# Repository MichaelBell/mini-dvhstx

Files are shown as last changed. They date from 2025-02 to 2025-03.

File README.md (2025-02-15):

# Mini RP2350 board for Digital Video

The RP2350's HSTX peripheral supports TMDS encoding, as needed for HDMI/DVI video.

The idea of this board is to provide a minimal board in a similar form factor to the Pico 2, but with an HDMI connector on it, to allow experimenting with HSTX and digital video.



My [DVI for HSTX](https://github.com/MichaelBell/dvhstx) library should be ideal for use with this board.

## Pinout

The left side is the same as the Pico, the right side is different (but somewhat related).

| Left Side | Right Side |
| --- | --- |
| GPIO 0 | VBUS |
| GPIO 1 | HDMI 5V |
| Ground | Ground |
| GPIO 2 | Not connected |
| GPIO 3 | +3V3 |
| GPIO 4 | GPIO 29 (ADC) |
| GPIO 5 | GPIO 28 (ADC) |
| Ground | Ground |
| GPIO 6 | GPIO 23 |
| GPIO 7 | GPIO 22 |
| GPIO 8 | SWD |
| GPIO 9 | SWCLK |
| Ground | Ground |
| GPIO 10 | |
| GPIO 11 | |
| HDMI HPD  | |

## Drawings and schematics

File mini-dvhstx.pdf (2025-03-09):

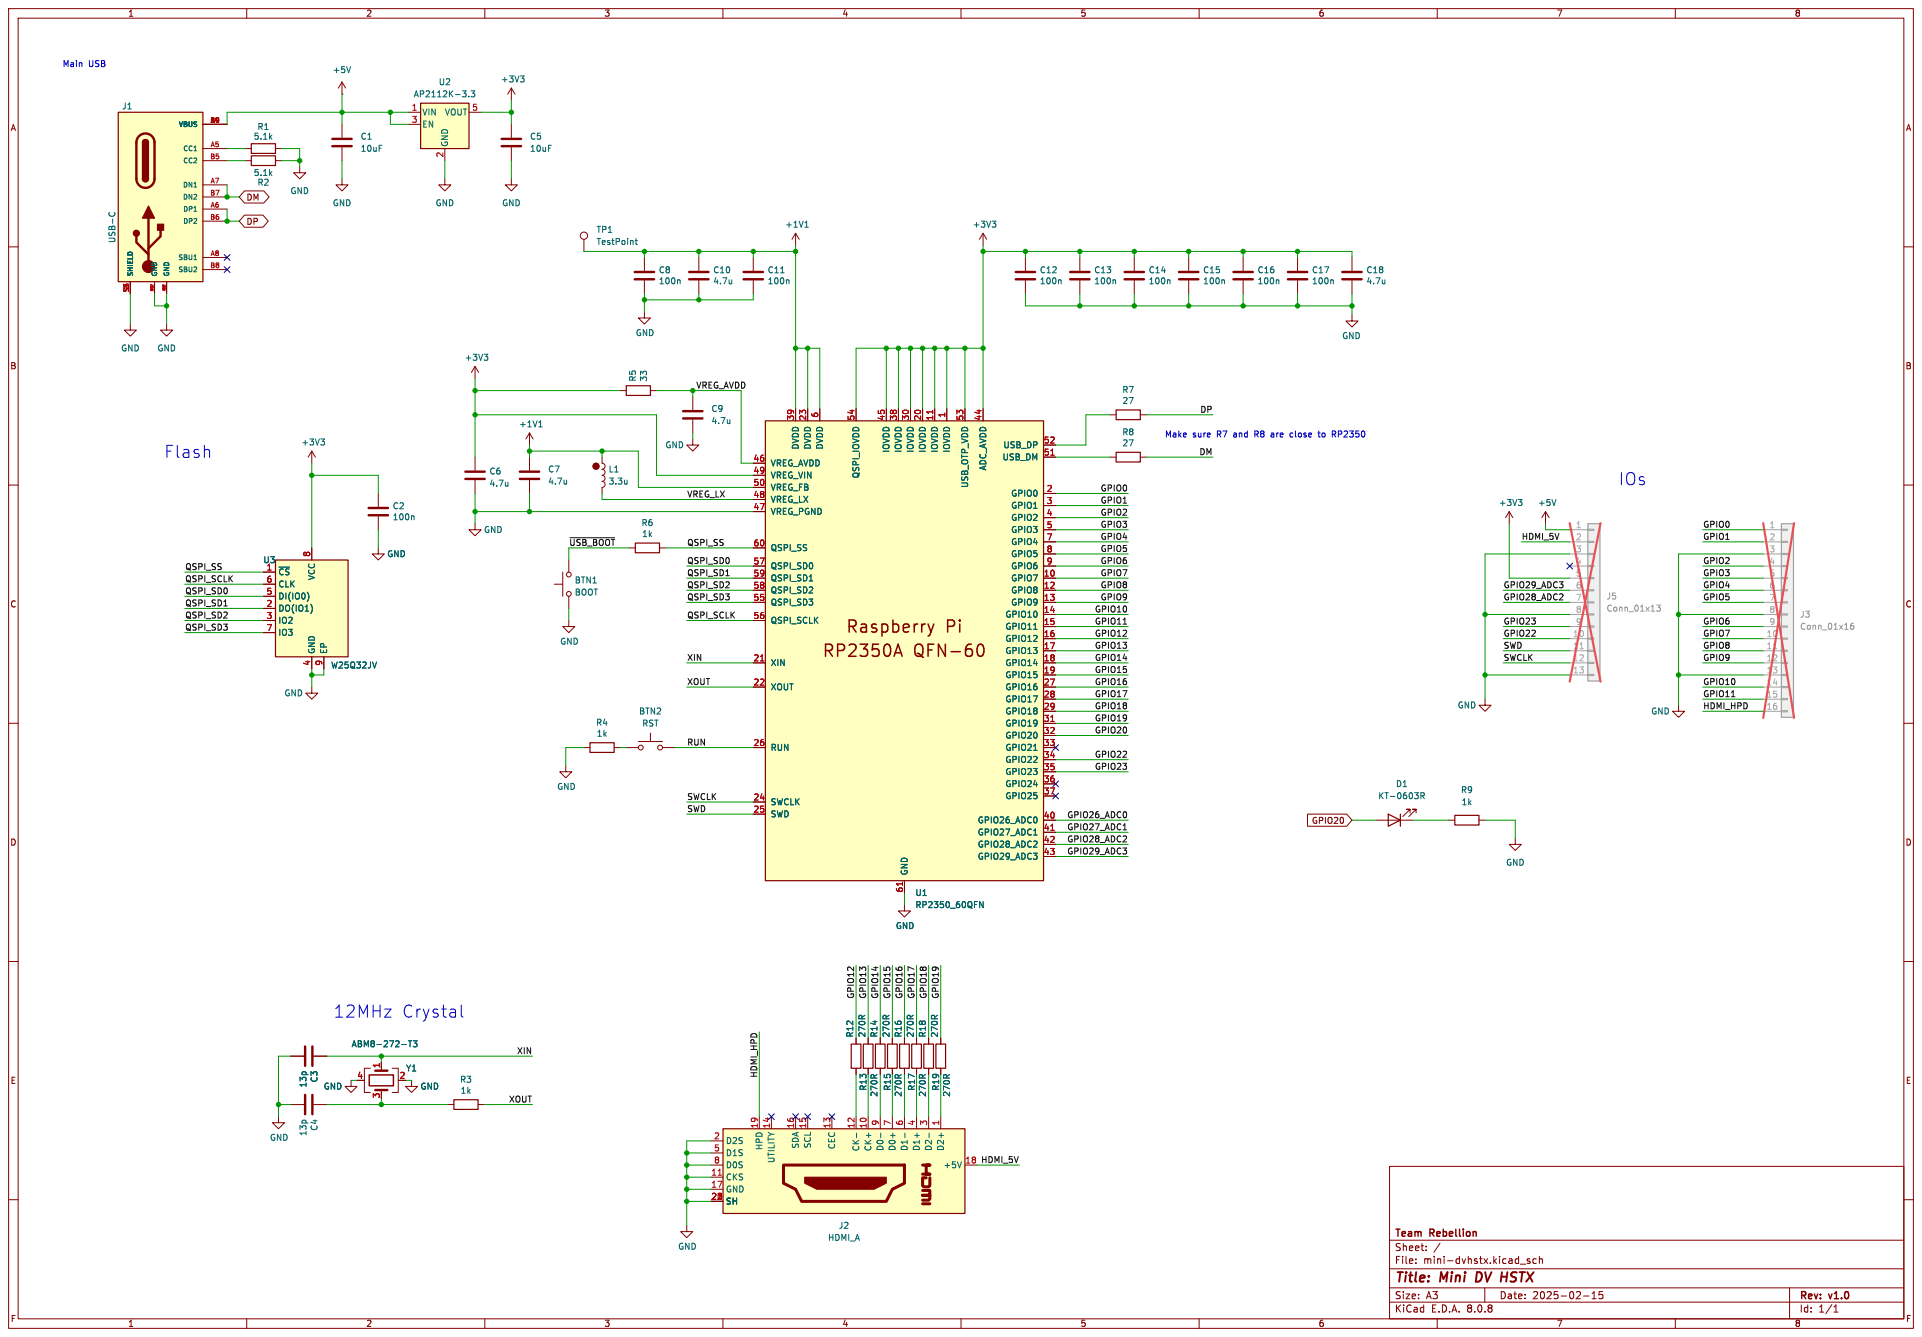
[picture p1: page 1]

1 CC1 A5 DP1 A6 DN1 A7 SBU1 A8 CC2 B5 DP2 B6 DN2 B7 SBU2 B8 SHIELD S34 GND A1 GND A12 VBUS A49 GND B1 GND B12 VBUS B49 SHIELD S1 J1 USB-C

1 GPIO7 10 IOVDD 11 GPIO8 12 GPIO9 13 GPIO10 14 GPIO11 15 GPIO12 16 GPIO13 17 GPIO14 18 GPIO15 19 GPIO0 2 IOVDD 20 XIN 21 XOUT 22 DVDD 23 SWCLK 24 SWD 25 RUN 26 GPIO16 27 GPIO17 28 GPIO18 29 GPIO1 3 IOVDD 30 GPIO19 31 GPIO20 32 GPIO21 33 GPIO22 34 GPIO23 35 GPIO24 36 GPIO25 37 IOVDD 38 DVDD 39 GPIO2 4 GPIO26_ADC0 40 GPIO27_ADC1 41 GPIO28_ADC2 42 GPIO29_ADC3 43 ADC_AVDD 44 IOVDD 45 VREG_AVDD 46 VREG_PGND 47 VREG_LX 48 VREG_VIN 49 GPIO3 5 VREG_FB 50 USB_DM 51 USB_DP 52 USB_OTP_VDD 53 QSPI_IOVDD 54 QSPI_SD3 55 QSPI_SCLK 56 QSPI_SD0 57 QSPI_SD2 58 QSPI_SD1 59 DVDD
U1 RP2350_60QFN IOVDD

1 CK+ 10 CKS 11 CK- 12 CEC 13 UTILITY 14 SCL 15 SDA 16 GND 17 +5V 18 HPD 19 D2S 2 SH 20123 D2- 3 D1+

Id: 1/1 Title: Mini DV HSTX

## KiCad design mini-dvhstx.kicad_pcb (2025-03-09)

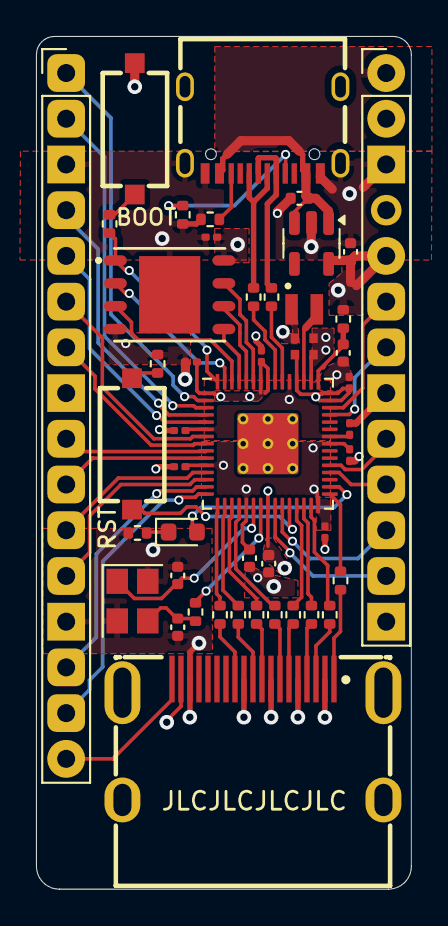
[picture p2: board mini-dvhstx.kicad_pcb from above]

Board: 4 copper layers, 20.8 x 47.4 mm, 48 parts (1 on the bottom side), 62 nets.

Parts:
BTN1: BOOT; SW-SMD_HX-TS-1101-C-W
BTN2: RST; SW-SMD_HX-TS-1101-C-W
C1, C5: 10uF; C_0402_1005Metric
C2, C8, C11, C12, C13, C14, C15, C16, C17: 100n; C_0201_0603Metric
C3, C4: 13p; C_0402_1005Metric
C6, C7: 4.7u; C_0402_1005Metric_small_pads
C9, C10, C18: 4.7u; C_0402_1005Metric
D1: KT-0603R; LED_0603_1608Metric
J1: USB-C; TYPE-C-SMD_MC-107DJ
J2: HDMI_A; HDMI-SMD_KH-HDMI-19P-CU
J3: Conn_01x16; PinHeader_1x15_P2.54mm_Vertical
J5: Conn_01x13; PinHeader_1x15_P2.54mm_Vertical
L1: 3.3u; L_pol_2016
R1, R2: 5.1k; R_0402_1005Metric
R3, R4, R6, R9: 1k; R_0402_1005Metric
R5: 33; R_0402_1005Metric
R7, R8: 27; R_0402_1005Metric
R12, R13, R14, R15, R16, R17, R18, R19: 270R; R_0402_1005Metric
TP1: TestPoint; TestPoint_Pad_2.0x2.0mm
U1: RP2350_60QFN; RP2350-QFN-60-1EP_7x7_P0.4mm_EP3.4x3.4mm_ThermalVias
U2: AP2112K-3.3; SOT-23-5
U3: W25Q32JV; WSON-8_L6.0-W5.0-P1.27-BL-EP
Y1: ABM8-272-T3; Crystal_SMD_3225-4Pin_3.2x2.5mm

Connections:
+1V1: C7.1, C8.1, C10.1, C11.1, L1.1, TP1.1, U1.6 (DVDD), U1.23 (DVDD), U1.39 (DVDD), U1.50 (VREG_FB)
+3V3: C2.1, C5.1, C6.1, C12.1, C13.1, C14.1, C15.1, C16.1, C17.1, C18.1, J5.5, R5.1, U1.1 (IOVDD), U1.11 (IOVDD), U1.20 (IOVDD), U1.30 (IOVDD), U1.38 (IOVDD), U1.44 (ADC_AVDD), U1.45 (IOVDD), U1.49 (VREG_VIN), U1.53 (USB_OTP_VDD), U1.54 (QSPI_IOVDD), U2.5 (VOUT), U3.8 (VCC)
+5V: C1.1, J1.A4 (VBUS), J1.A9 (VBUS), J5.1, U2.1 (VIN), U2.3 (EN)
/GPIO0: J3.1, U1.2 (GPIO0)
/GPIO1: J3.2, U1.3 (GPIO1)
/GPIO2: J3.4, U1.4 (GPIO2)
/GPIO3: J3.5, U1.5 (GPIO3)
/GPIO4: J3.6, U1.7 (GPIO4)
/GPIO5: J3.7, U1.8 (GPIO5)
/GPIO6: J3.9, U1.9 (GPIO6)
/GPIO7: J3.10, U1.10 (GPIO7)
/GPIO8: J3.11, U1.12 (GPIO8)
/GPIO9: J3.12, U1.13 (GPIO9)
/GPIO10: J3.14, U1.14 (GPIO10)
/GPIO11: J3.15, U1.15 (GPIO11)
/GPIO12: R12.1, U1.16 (GPIO12)
/GPIO13: R13.1, U1.17 (GPIO13)
/GPIO14: R14.1, U1.18 (GPIO14)
/GPIO15: R15.1, U1.19 (GPIO15)
/GPIO16: R16.1, U1.27 (GPIO16)
/GPIO17: R17.1, U1.28 (GPIO17)
/GPIO18: R18.1, U1.29 (GPIO18)
/GPIO19: R19.1, U1.31 (GPIO19)
/GPIO22: J5.10, U1.34 (GPIO22)
/GPIO23: J5.9, U1.35 (GPIO23)
/GPIO28_ADC2: J5.7, U1.42 (GPIO28_ADC2)
/GPIO29_ADC3: J5.6, U1.43 (GPIO29_ADC3)
/HDMI_5V: J2.18 (+5V), J5.2
/HDMI_HPD: J2.19 (HPD), J3.16
/QSPI_SCLK: U1.56 (QSPI_SCLK), U3.6 (CLK)
/QSPI_SD0: U1.57 (QSPI_SD0), U3.5 (DI(IO0))
/QSPI_SD1: U1.59 (QSPI_SD1), U3.2 (DO(IO1))
/QSPI_SD2: U1.58 (QSPI_SD2), U3.3 (IO2)
/QSPI_SD3: U1.55 (QSPI_SD3), U3.7 (IO3)
/QSPI_SS: R6.1, U1.60 (QSPI_SS), U3.1 (~CS)
/RUN: BTN2.2, U1.26 (RUN)
/SWCLK: J5.12, U1.24 (SWCLK)
/SWD: J5.11, U1.25 (SWD)
/VREG_AVDD: C9.1, R5.2, U1.46 (VREG_AVDD)
/VREG_LX: L1.2, U1.48 (VREG_LX)
/XIN: C3.1, U1.21 (XIN), Y1.1
/XOUT: R3.1, U1.22 (XOUT)
/~USB_BOOT: BTN1.2, R6.2
DM: J1.A7 (DN1), J1.B7 (DN2), R8.1
DP: J1.A6 (DP1), J1.B6 (DP2), R7.1
GND: BTN1.1, C1.2, C2.2, C3.2, C4.2, C5.2, C6.2, C7.2, C8.2, C9.2, C10.2, C11.2, C12.2, C13.2, C14.2, C15.2, C16.2, C17.2, C18.2, J1.1 (SHIELD), J1.A1 (GND), J1.A12 (GND), J2.2 (D2S), J2.5 (D1S), J2.8 (D0S), J2.11 (CKS), J2.17 (GND), J2.20 (SH), J2.21 (SH), J2.22 (SH), J2.23 (SH), J3.3, J3.8, J3.13, J5.3, J5.8, J5.13, R1.2, R2.2, R4.2, R9.2, U1.47 (VREG_PGND), U1.61 (GND), U2.2 (GND), U3.4 (GND), U3.9 (EP), Y1.2, Y1.4
GPIO20: D1.2 (A), U1.32 (GPIO20)
unnamed: BTN2.1, R4.1
unnamed: C4.1, R3.2, Y1.3
unnamed: D1.1 (K), R9.1
unnamed: J1.A5 (CC1), R1.1
unnamed: J1.B5 (CC2), R2.1
unnamed: J2.10 (CK+), R13.2
unnamed: J2.12 (CK-), R12.2
unnamed: J2.7 (D0+), R15.2
unnamed: J2.9 (D0-), R14.2
unnamed: J2.4 (D1+), R17.2
unnamed: J2.6 (D1-), R16.2
unnamed: J2.1 (D2+), R19.2
unnamed: J2.3 (D2-), R18.2
unnamed: R8.2, U1.51 (USB_DM)
unnamed: R7.2, U1.52 (USB_DP)

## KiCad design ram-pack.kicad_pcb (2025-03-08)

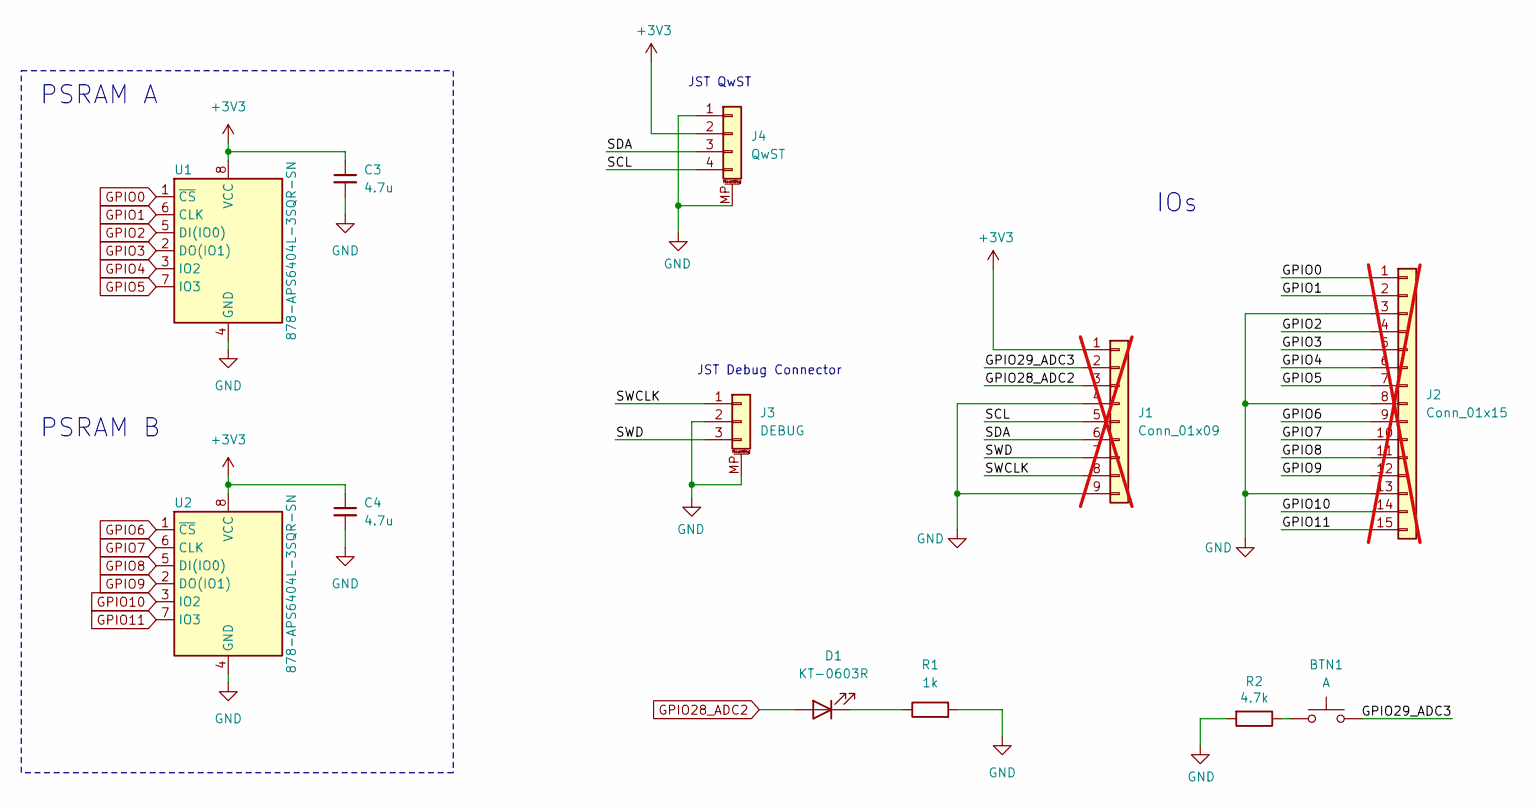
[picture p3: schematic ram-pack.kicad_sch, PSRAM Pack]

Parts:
BTN1: A; SW-SMD_HX-TS-1101-C-W; JLC C36498960
C3, C4: 4.7u; C_0402_1005Metric; MPN C0402C105M9PAC
D1: KT-0603R; LED_0603_1608Metric; JLC C2286
J1: Conn_01x09; PinSocket_1x09_P2.54mm_Vertical; not fitted
J2: Conn_01x15; PinSocket_1x15_P2.54mm_Vertical; not fitted
J3: DEBUG; JST_SH_SM03B-SRSS-TB_1x03-1MP_P1.00mm_Horizontal; JLC C160403
J4: QwST; JST_SH_BM04B-SRSS-TB_1x04-1MP_P1.00mm_Vertical; JLC C160390
R1: 1k; R_0402_1005Metric
R2: 4.7k; R_0402_1005Metric
U1, U2: 878-APS6404L-3SQR-SN; SOP-8_3.9x4.9mm_P1.27mm; MPN APS6404L-3SQR-SN; JLC C5333729

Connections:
+3V3: C3.1, C4.1, J1.1, J4.2, U1.8 (VCC), U2.8 (VCC)
/GPIO29_ADC3: BTN1.2, J1.2
/SCL: J1.5, J4.4
/SDA: J1.6, J4.3
/SWCLK: J1.8, J3.1
/SWD: J1.7, J3.3
GND: C3.2, C4.2, J1.4, J1.9, J2.3, J2.8, J2.13, J3.2, J3.MP (MountPin), J4.1, J4.MP (MountPin), R1.2, R2.2, U1.4 (GND), U2.4 (GND)
GPIO0: J2.1, U1.1 (~CS)
GPIO1: J2.2, U1.6 (CLK)
GPIO2: J2.4, U1.5 (DI(IO0))
GPIO3: J2.5, U1.2 (DO(IO1))
GPIO4: J2.6, U1.3 (IO2)
GPIO5: J2.7, U1.7 (IO3)
GPIO6: J2.9, U2.1 (~CS)
GPIO7: J2.10, U2.6 (CLK)
GPIO8: J2.11, U2.5 (DI(IO0))
GPIO9: J2.12, U2.2 (DO(IO1))
GPIO10: J2.14, U2.3 (IO2)
GPIO11: J2.15, U2.7 (IO3)
GPIO28_ADC2: D1.2 (A), J1.3
unnamed: BTN1.1, R2.1
unnamed: D1.1 (K), R1.1

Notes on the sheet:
IOs
JST QwST
JST Debug Connector
PSRAM B
PSRAM A

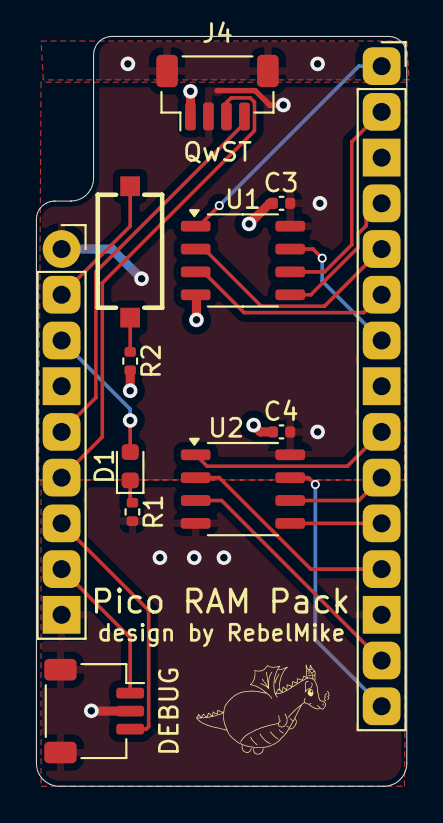
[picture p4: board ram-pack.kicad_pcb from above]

Board: 4 copper layers, 20.6 x 41.7 mm, 12 parts (0 on the bottom side), 22 nets.

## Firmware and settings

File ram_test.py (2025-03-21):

from machine import Pin
import time
import random

@rp2.asm_pio(out_shiftdir=0, autopull=True, pull_thresh=8, autopush=True, push_thresh=8, sideset_init=(rp2.PIO.OUT_LOW,), out_init=rp2.PIO.OUT_LOW)
def spi_cpha0():
    out(pins, 1)             .side(0x0)
    in_(pins, 1)             .side(0x1)

class PIOSPI:
    def __init__(self, sm_id, pin_mosi, pin_miso, pin_sck, freq=1000000):
        self._sm = rp2.StateMachine(sm_id, spi_cpha0, freq=2*freq, sideset_base=Pin(pin_sck), out_base=Pin(pin_mosi), in_base=Pin(pin_miso))
        self._sm.active(1)
        Pin(pin_miso, Pin.IN)

    @micropython.native
    def write(self, wdata):
        first = True
        for b in wdata:
            self._sm.put(b, 24)
            if not first:
                self._sm.get()
            else:
                first = False
        self._sm.get()
        
    def read(self, n):
        return self.write_read_blocking([0,]*n)

    @micropython.native
    def readinto(self, rdata):
        self._sm.put(0)
        for i in range(len(rdata)-1):
            self._sm.put(0)
            rdata[i] = self._sm.get()
        rdata[-1] = self._sm.get()

    @micropython.native
    def write_read_blocking(self, wdata):
        rdata = bytearray(len(wdata))
        i = -1
        for b in wdata:
            self._sm.put(b, 24)
            if i >= 0:
                rdata[i] = self._sm.get()
            i += 1
        rdata[i] = self._sm.get()
        return rdata


def test_psram(spi, sel):

    sel.on()

    CMD_WRITE = 0x02
    CMD_READ = 0x03

    def spi_cmd(data, sel, dummy_len=0, read_len=0):
        dummy_buf = bytearray(dummy_len)
        read_buf = bytearray(read_len)
        
        sel.off()
        spi.write(bytearray(data))
        if dummy_len > 0:
            spi.readinto(dummy_buf)
        if read_len > 0:
            spi.readinto(read_buf)
        sel.on()
        
        return read_buf

    def spi_cmd2(data, data2, sel):
        sel.off()
        spi.write(bytearray(data))
        spi.write(data2)
        sel.on()

    buf = bytearray(8)
    
    for j in range(1024):
        addr = random.randint(0, 8 * 1024 * 1024 - 8)
        for i in range(8):
            buf[i] = random.randint(0, 255)

        spi_cmd2([CMD_WRITE, addr >> 16, (addr >> 8) & 0xFF, addr & 0xFF], buf, sel)
        data = spi_cmd([CMD_READ, addr >> 16, (addr >> 8) & 0xFF, addr & 0xFF], sel, 0, 8)

        for i in range(8):
            if buf[i] != data[i]:
                raise Exception(f"Error {buf[i]} != {data[i]} at addr {addr}+{i}")
            
    print("PSRAM OK")

sel = Pin(0, Pin.OUT, value=1)
spi = PIOSPI(0, 2, 3, 1, freq=15000000)

test_psram(spi, sel)

sel = Pin(6, Pin.OUT, value=1)
spi = PIOSPI(0, 8, 9, 7, freq=15000000)

test_psram(spi, sel)

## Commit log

2025-02-15 Complete routing
    [mini-dvhstx.kicad_pcb, mini-dvhstx.kicad_sch]
2025-02-15 Add schematic
    [mini-dvhstx.kicad_pcb, mini-dvhstx.kicad_sch]
2025-02-16 RAM pack
    [mini-dvhstx.kicad_pcb, ram-pack.kicad_pcb, ram-pack.kicad_sch]
2025-03-08 Moving towards v1
    [mini-dvhstx.kicad_pcb, mini-dvhstx.kicad_sch, ram-pack.kicad_pcb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]
2025-03-09 First version
    [mini-dvhstx.kicad_pcb]
